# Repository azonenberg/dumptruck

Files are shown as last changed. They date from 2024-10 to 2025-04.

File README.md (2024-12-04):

# dumptruck
FPGA based dumper for flashes and more

## Main PCB errata

Bugs in the v0.1 PCB

* 1.0V shunt resistor is missing a zone fill. Will monitor droop under load and see if we need to add top layer power path.
* U33 is way too close to J10. Seems to have fit OK, not touching for now, but tough to assemble.
* INIT_B and PROG_B on FPGA are 1.8V signals but we try to drive with 3.3 from supervisor! Rework: add pull to 1.8V on board, open drain in super firmware
* JTAG connector VCC is connected to 3.3V. We need to supply 1.8 here. Temporary workaround: six pin extension cable, pass through JTAG + GND and supply 1.8V to dongle externally. Long term fix: interposer board
* DONE on FPGA is 1.8V signal driving 3.3V input on supervisor, too low for Vih. Rework: add 1.8V gate drive NMOS to pull low when done, invert logic in firmware

TODO: add HF caps to VCAP on STM32

## Breakout board errata

* v0.1 of parallel-nor-csp56 and dip8-qspi had EEPROM at 0xa0 which conflicted with MAC address EEPROM. Future breakouts use 0xa2 to avoid conflict

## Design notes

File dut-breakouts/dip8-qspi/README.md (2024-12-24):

# DIP8 QSPI flash

This board is intended to host either a DIP-8 QSPI flash (directly soldered or socketed), or a ZIF socket with
DIP-8 pinout for SOIC, DFN, etc.

Tested and validated sockets:
* DFN-8 (both 5x6 and 6x8 available) https://www.aliexpress.us/item/3256804610913861.html
* Narrow (150 mil) SOIC-8 https://www.aliexpress.us/item/2255799898445538.html

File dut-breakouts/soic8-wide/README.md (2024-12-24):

# soic8-wide

Breakout for wide (208 mil) SOIC-8

Designed for this socket https://www.aliexpress.us/item/3256807343973730.html

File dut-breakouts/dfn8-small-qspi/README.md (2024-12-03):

# dfn8-small-qspi

Breakout for small (5x6 mm) DFN-8 QSPI flashes.

Designed for this socket https://www.aliexpress.us/item/3256805075607192.html

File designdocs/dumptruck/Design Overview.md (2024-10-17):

* Powered by USB-C, CC pin tieoff for 900 mA power budget @ 5V, no PD, no USB data
	* One LTC3374A supplies all rails. 8 outputs among 4 phases
		* Have 3 in stock
	* Always-on 3V3_SB rail
	* Remainder (1V0, 1V2, 1V8, 2V5, 3V3) sequenced by supervisor
* STM32L431 rail sequencer / reset supervisor
	* QFN32 or QFN48 package depending on IO needs
	* GPIO for soft reset, power on/off
	* Have 7 or 8 in inventory depending on which package we go with
* Xilinx XC7S100-1FGGA484C
	* Have 3 in stock
	* Data link to host PC: 1000baseT via KSZ9031RNX
		* Have 13 in stock
	* HyperRAM footprint in case we want buffer on the FPGA
		* Infineon S27KS0642GABHI030
			* HyperBUS, 1.8V only, 200 MHz, 64 Mbit
			* Have 10 in stock
	* Boot flash: need minimum 32 Mbit
		* ISSI IS25WP256D-JLLE
			* 256 Mbit so room for multi-boot images
			* QSPI, 1.8V only, 8x6 WSON
			* Have 4 in stock
* STM32H735 as main processor
	* Have 9 in stock
	* HyperRAM in case we want buffer on the MCU?
		* Will need to account for OctoSPI errata, but this is probably OK if we're only using it for bulk data transfers.
		* Do not have any 3.3V HyperRAM in inventory. Leave DNP'd footprint
	* FMC to FPGA as primary I/O interface
	* AT24MAC402 for MAC address
		* Have a ton of these
* Four separate socket connectors (interface TBD, 0.1" header or something else?) for DUT ZIF sockets / BGA breakouts. Each one goes to a dedicated FPGA IO bank running at the target VCCO
* External 0.1" header with jumpers for muxing one of the four suitable IO rails as DUT Vcore
	* Can also feed externally generated Vcore in for unusual voltage requirements
	* No on-board variable Vcore supply
	* ADC input from Vcore to MCU so we know which is selected
* Software controlled load switch from muxed Vcore to DUT socket using NCP45525IMNTWG-H
	* Slew rate controlled, load discharge, active high enable
	* Requires external 3.3V supply
	* Can switch loads from 0.5 to 13.5V

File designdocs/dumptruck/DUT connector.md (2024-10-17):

* Samtec BSE-040 (80 contacts total)
* 8x support signals
	* 2x vcore
	* 2x vccio
	* Presence detect: pulled weakly low on host, tie to 3v3 on socket
	* 3v3 for ID EEPROM
	* I2C for ID EEPROM
* 50x GPIOs
* 22 grounds

## Pinout
1-14 support stuff, that leaves 66 left
50x GPIO + 16 grounds = one ground per 3.125 signals

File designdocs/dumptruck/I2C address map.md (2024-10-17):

## Supervisor bus

* INA230s:
	* VBUS: 0x80
	* 3V3_SB: 0x82
	* 3V3: 0x84
	* 2V5: 0x86
	* 1V8: 0x88
	* 1V2: 0x8a
	* 1V0: 0x8c
	* DUT_VDD: 0x8e
	* DUT_VCCIO 3V3: 0x90
	* DUT_VCCIO 2V5: 0x92
	* DUT_VCCIO 1V8: 0x94
	* DUT_VCCIO 1V2: 0x96
## Main MCU bus
* MAC EEPROM: 0xa0, 0xb0
* Socket ID EEPROM: 0xa2

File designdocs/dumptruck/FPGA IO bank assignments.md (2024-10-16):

## Available banks

We have seven banks available: 13, 14, 15, 16, 34, 35, 36 plus config bank 0.

All banks are HR and generally drop-in interchangeable, EXCEPT:
* QSPI flash pins are in bank 14
* Bank 13 has only 38 pins of 50 bonded out
## Requirements
* DUT sockets
	* Dedicate one full bank to each socket
	* Don't yet know how many pins we'll actually break out
* Boot flash
	* Bank 14, LVCMOS18, needs 4x SPI data + CS. CCLK is in bank 0
	* This means bank 0 must be LVCMOS18 as well (i.e. JTAG is 1.8V)
* HyperRAM
	* 12 pins, LVCMOS18
* Ethernet
	* 14 pins for RGMII + MDIO, assume reset driven by MCU not FPGA
	* Can do whatever voltage, but LVCMOS18 is least power
* FPGA - MCU interface
	* All LVCMOS33 to interface to MCU at full voltage
	* If we hook up optional addr/enable bits, we get 37 pins
	* Signals:
		* clk
		* nwait
		* noe
		* ad\[15:0\]
		* nwe
		* nbl\[1:0\]
		* nl_nadv
		* addr_hi\[25:0\]
			* Max of 26 address lines available, 15:0 are shared with AD so we can add up to another 10. Pin out as many as we can comfortably route
		* ne\[3:0\]
			* ne1 is the most important if we are using a standard config
			* Can't hurt to hook up the others if we have sufficient pins
## Tentative bank assignments
* Bank 13: 1.8V, 0 / 38 used
* Bank 14: 1.8V, 32 / 50 used
	* Boot flash (5)
	* HyperRAM (12)
	* RGMII (14 including 1 clock)
	* 25 MHz system primary clock
* Bank 15: 3.3V, 50 / 50 used
	* FMC interface
* Bank 16: 3.3V, ?? / 50 used
	* DUT socket
* Bank 36: 2.5V, ?? / 50 used
	* DUT socket
* Bank 35:  1.8V, ?? / 50 used
	* DUT socket
* Bank 34: 1.2V, ?? / 50 used
	* DUT socket

Rationale:
* Bank 14 must be 1.8V for boot flash, can shove basically all other non-MCU IO there
* Bank 13 has less pins, leave it for overflow capacity
* We want the DUT sockets in adjacent banks for routability. With 14 occupied by control stuff and 13 too small, we need to choose 4 out of 5 (34, 35, 36, 16, 15) as the DUT-facing banks. Using 15 as the other control bank seems logical so all control logic is on the same side of the FPGA.
* Bank 15 is 100% used for MCU interface and runs at 3.3V. Putting the 3.3V DUT bank in 16 simplifies power routing.
* Bank 36 is off in a corner so easier to route odd power voltage to
* Bank 35 is directly across from 14 separated by the FPGA core. Both banks, plus VCCAUX, need 1.8V so we can route a 1.8V polygon all the way across.
* Bank 34 is also in a corner so easy to route an odd voltage to

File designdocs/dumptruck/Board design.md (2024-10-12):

## Physical floorplan
* USB-C and Ethernet connectors along east edge
* FPGA near center with A1 in northwest corner
* MCU northeast
* Ethernet and boot flash southeast
* DUT sockets to west. May have overlapping mounting footprints as only one socket of the four will be mated at any given time
* Debug connectors along south edge
	* Bank 13 unused so can easily escape JTAG through this region
* Probably want power regulation in southeast
	* Can have a 3.3V pour snake around the edge of the board to get to the MCU area
	* Easy access to PHY and FPGA center
	* Maybe have 2.5V hook north and west to get to the bank there
## Fab / stackup
* We have a lot of power domains that need to get around
	* 3.3V only used by northeast area (MCU + DUT bank 16 IOs)
	* 2.5V used by northwest corner of FPGA plus PHY
		* Unless we run the PHY AVDDH at 3.3?
		* That might be easier since we have 3.3 in that general area from the MCU already, but will cost another ~75 mW of power
	* 1.8V used by center of FPGA, Ethernet, boot flash
	* 1.2V used by southwest corner of FPGA and Ethernet
	* 1.0V used by FPGA core only, feed in from south under bank 13 since no IOs there?
* Minimum one dedicated power layer but ideally would like some power on another layer
* Staying 6L would be nice, but tricky
	* That would allow oshpark 6L, this is slow enough fiber weave effect from the 106 PP is no factor
	* Possible stackup: SGS SGS with power pours on L3/L4 around signals?
		* Not great from an impedance matching perspective since the ground will couple and act as a CPWG but not provide a clean return path
		* Can't get large clearances from signals because of the BGA via field
* 8L probably better?
	* Possible stackup: SGS PP SGS
	* I really don't think 10L SGS GPPG SGS is necessary for this, but we do want four signal layers

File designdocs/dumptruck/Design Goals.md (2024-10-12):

* This is a "junk box build". Use components I have in inventory as much as possible, even if they're not necessarily optimal, unless there is a well defined reason not to.
* Be able to dump (or, with suitable firmware, program) any memory-ish chip I may encounter given an appropriate breakout adapter or ZIF socket
	* I2C EEPROM
	* (Q)SPI flash
	* Raw ONFI NAND
	* eMMC

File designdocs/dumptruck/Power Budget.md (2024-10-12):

## Breakdown

Target power budget: 900 mA @ 5V using USB3 host on type-C connector 4.5W

* KSZ9031 assuming 2.5V AVDDH: 452 mW
	* 1.2V @ 221 mA = 262 mW
	* 1.8V @ 23.6 mA = 43 mW
	* ONE OF
		* 2.5V @ 58.8 mA = 147 mW
		* 3.3V @ 67.4 mA = 222 mW
* STM32H735:
	* Worst case if using SMPS: 3.3V @ 130 mA = 429 mW
* Whatever the DUT uses
	* Random modern NAND (per die) total 546 mW
		* 2.5 or 3.3V Vcc @ 100 mA = 330 mW
		* 1.2V Vccq @  180 mA = 216 mW
* So far we're at total of 1.42W plus conversion losses
* XC7K160T considered since i had some gathering dust, but would be over power budget
* XC7S100-1FGGA484I: 1.78W plus whatever design uses beyond boot surge
	* Has 7 IO banks vs 8
	* 16K slices vs 25K
	* 120 BRAMs vs 325 (still has 480 kB SRAM)
	* Both have 8 CMTs, we dont care about DSPs
	* No GTX but we weren't gonna use those anyway
	* Should be more than big enough
	* Minimum power: 1.78W 
		* 148 + 9mA @ 1V0 + 300 + 60 during boot = 517 mW
		* 43 mA @ 1V8 + 140 during boot = 329 mW
		* No GTX supplies
		* No VCXAUX_IO
		* 4 mA VCCO + 40 mA per bank = 284 mA
			* Assume worst case 3.3V this is 937 mW
* So assuming design doesn't use much beyond boot surge, total power budget is 3.2W plus conversion losses. Comfortably fits in 4.5W target
* Maybe use a bit more for a HyperRAM on the STM32 if we wanted to play with that for lulz
* Add the usual small STM32L431 for rail sequencing and reset, this doesn't need much juice
* FPGA boot flash is negligible
## Rail Targets
* 1V0: 1A (~500 mA FPGA)
* 1V2: 1A (221 mA PHY + one FPGA VCCO bank)
* 1V8: 1A (180 mA FPGA + PHY IO + one FPGA VCCO bank)
* 2V5: 1A (60 mA PHY + one FPGA VCCO bank)
* 3V3: 1A (130 mA MCU + one FPGA VCCO bank)

Plus whatever the DUT actually needs on Vcore but we assume that's small
* Use MUN12AD03-SE for each rail? Easy and tiny, but really wants 12V in and has minimum Vin of 4.5V. Won't handle Vbus droop well.
* Use LTC3374A? Might be a bit noisier but this is a digital board without tight ripple requirements. It can do every rail comfortably, we can gang several phases to improve efficiency. This is probably best bet.

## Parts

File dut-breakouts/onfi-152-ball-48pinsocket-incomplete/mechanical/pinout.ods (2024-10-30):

BGA ball | Socket pin | Function | Cap C10 Is VCC to GND | Missing socket pins
D11 | -- | VCCQ |  | A1 | nc?
D3 | C2 | VCCQ |  | A3 | nc?
D4 | C4 | VCCQ |  | A5 | nc?
D5 | B3 | DQ3_1 |  | A7 | nc?
D6 | E1 | GND |  | B1 | nc?
D8 | F1 | VCC |  | B5 | nc?
D9 |  | DQ4_1 |  | B8 | nc?
E10 |  | DQ5_1 |  | C6 | nc?
E11 | A4 | GND |  | C8 | nc?
E3 | E8 | GND |  | D1 | nc?
E4 | C3 | DQ2_1 |  | E2 | nc?
E5 | D4 | GND |  | E5 | nc?
E6 | B4 | DQS_1_P |  | F2 | nc?
E8 |  | RE_1_N |  | F8 | nc?
E9 | C1 | GND
F10 |  | DQ6_1
F11 |  | DQ7_1
F3 |  | DQ0_1
F4 | A2 | DQ1_1
F5 |  | DQS1_N
F6 |  | RE_1_P
F8 |  | WE1_N
F9 |  | VREF_1
G10 | -- | VCCQ
G11 | -- | GND
G3 | A8 | GND
G4 | -- | VCCQ
G5 | E3 | ALE_1
G6 | D3 | CLE_1
H10 |  | RZQ_1
H5 | D2 | WP1_N
H8 | E4 | CE1_1_N
H9 | F6 | CE0_1_N
J10 | C5 | VCC
J11 | -- | GND
J3 | -- | GND
J4 | F5 | VCC
J5 | F7 | R_B0_0
J6 | D7 | R_B1_0
J8 | E7 | R_B1_1
J9 | D6 | R_B0_1
K4 |  | RZQ_0
K5 | D5 | CE0_0_N
K6 | F4 | CE1_0_N
K8 |  | VPP
K9 |  | WP0_N
L10 | -- | VCCQ
L11 | -- | GND
L2 | -- | GND
L4 | -- | VCCQ
L8 |  | CLE_0
L9 |  | ALE_0
M10 |  | DQ1_0
M11 | B2 | DQ0_0
M3 | B7 | DQ7_0
M4 | C7 | DQ6_0
M5 |  | VREF_0
M6 | F3 | WE_0_N
M8 |  | RE_0
M9 |  | DQS_0_N
N10 |  | DQ2_0
N11 | -- | GND
N3 | -- | GND
N4 | A6 | DQ5_0
N5 | -- | GND
N6 | E6 | RE_0_N
N8 |  | DQS_0_P
N9 | -- | GND
P10 | -- | VCCQ
P11 | -- | VCCQ
P3 | -- | VCCQ
P4 | -- | VCCQ
P5 | B6 | DQ4_0
P6 | D8 | VCC
P8 | -- | GND
P9 |  | DQ3_0

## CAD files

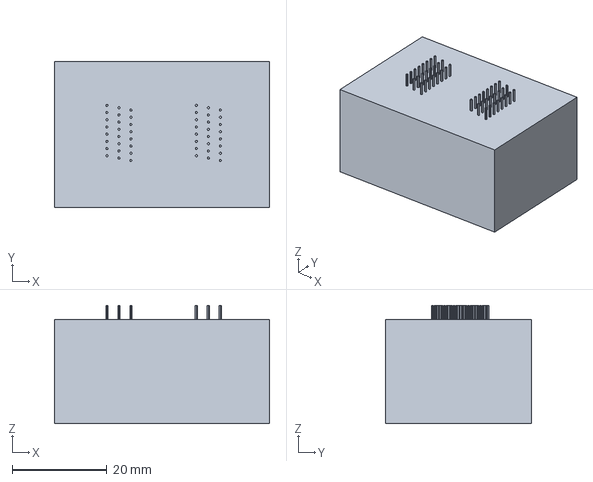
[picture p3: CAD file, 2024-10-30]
dut-breakouts/onfi-152-ball-48pinsocket-incomplete/mechanical/onfi-152-socket.step
45.5 x 31.0 x 25.0 mm

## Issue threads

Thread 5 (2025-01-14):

Improbable VDD voltage reported by CLI during dump

lainy, 2025-01-14:
```
[2000-02-01T04:49:13.9866] Power on request
[2000-02-01T04:49:13.9969]     VCCIO:  3.323V, 0.000A
[2000-02-01T04:49:13.9969]     VDD:    63.479V, 6.168A
[2000-02-01T04:49:13.9969]     VCCIO delta: 23 mV (OK)
```

azonenberg, 2025-01-15:
Likely related to communication between supervisor and main MCU. Could also be solder issue on one of the INA230s (U8, northeast corner).

Can you paste the output of "show hardware" in the CLI when the board is idle (not dumping)?

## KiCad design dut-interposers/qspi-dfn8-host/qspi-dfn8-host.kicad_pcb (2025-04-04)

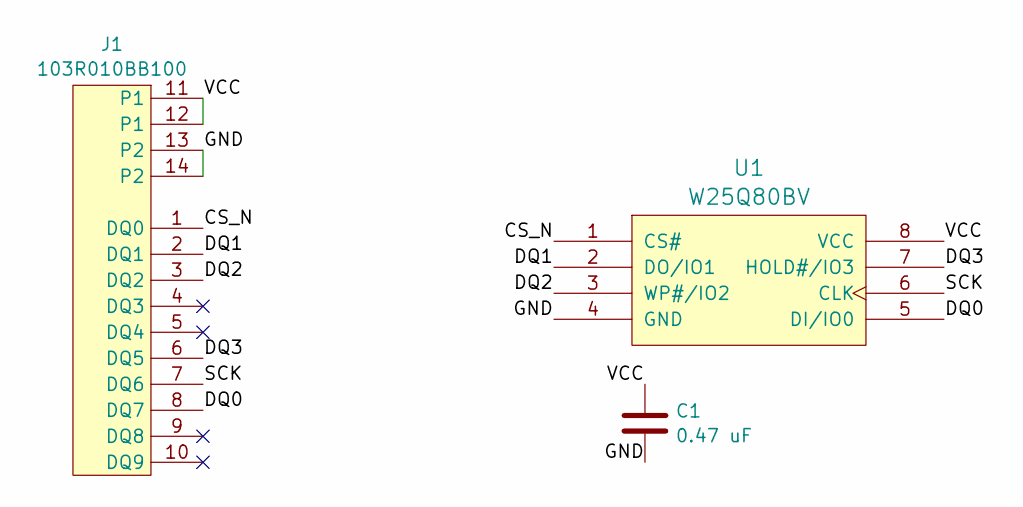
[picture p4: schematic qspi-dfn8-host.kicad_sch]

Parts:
C1: 0.47 uF; EIA_0402_CAP_NOSILK
J1: 103R010BB100; CONN_AMPHENOL_103R010BB100
U1: W25Q80BV; DFN_8_0.5MM_2x3MM_TALL

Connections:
/CS_N: J1.1 (DQ0), U1.1 (CS#)
/DQ0: J1.8 (DQ7), U1.5 (DI/IO0)
/DQ1: J1.2 (DQ1), U1.2 (DO/IO1)
/DQ2: J1.3 (DQ2), U1.3 (WP#/IO2)
/DQ3: J1.6 (DQ5), U1.7 (HOLD#/IO3)
/GND: C1.2, J1.13 (P2), J1.14 (P2), U1.4 (GND)
/SCK: J1.7 (DQ6), U1.6 (CLK)
/VCC: C1.1, J1.11 (P1), J1.12 (P1), U1.8 (VCC)

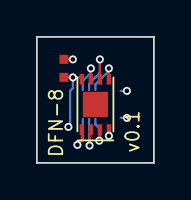
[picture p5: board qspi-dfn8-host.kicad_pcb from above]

Board: 4 copper layers, 6.5 x 7.0 mm, 3 parts (1 on the bottom side), 8 nets.

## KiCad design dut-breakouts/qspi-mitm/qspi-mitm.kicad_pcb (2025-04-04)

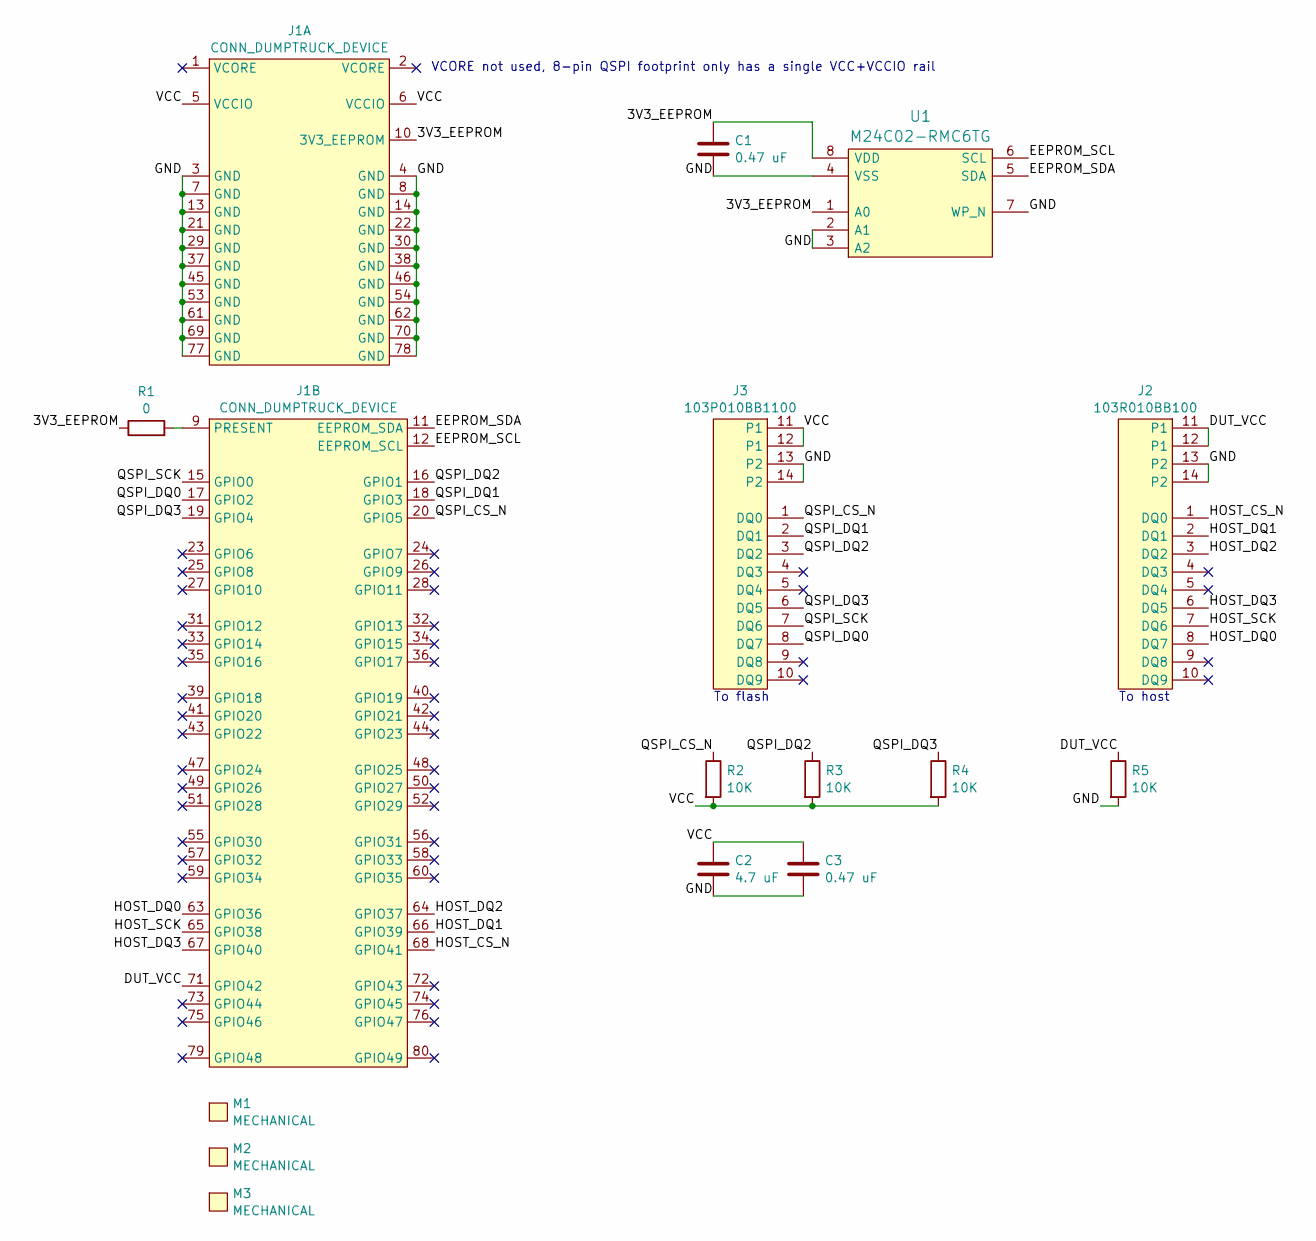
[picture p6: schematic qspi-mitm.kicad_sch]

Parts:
C1, C3: 0.47 uF; EIA_0402_CAP_NOSILK
C2: 4.7 uF; EIA_0603_CAP_NOSILK
J1: CONN_DUMPTRUCK_DEVICE; CONN_SAMTEC_BSE-040-01-L-D-A-TR
J2: 103R010BB100; CONN_AMPHENOL_103R010BB100
J3: 103P010BB1100; CONN_AMPHENOL_103P010BB100
M1: MECHANICAL; Logo_silk_ROHS_5x2.8mm
M2: MECHANICAL; Logo_silk_OSHW_6x6mm
M3: MECHANICAL; Logo_silk_WEEE_3.4x5mm
R1: 0; EIA_0402_RES_NOSILK
R2, R3, R4, R5: 10K; EIA_0402_RES_NOSILK
U1: M24C02-RMC6TG; DFN_8_0.5MM_2x3MM_TALL

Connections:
/3V3_EEPROM: C1.1, J1.10 (3V3_EEPROM), R1.1, U1.1 (A0), U1.8 (VDD)
/DUT_VCC: J1.71 (GPIO42), J2.11 (P1), J2.12 (P1), R5.1
/EEPROM_SCL: J1.12 (EEPROM_SCL), U1.6 (SCL)
/EEPROM_SDA: J1.11 (EEPROM_SDA), U1.5 (SDA)
/GND: C1.2, C2.2, C3.2, J1.3 (GND), J1.4 (GND), J1.7 (GND), J1.8 (GND), J1.13 (GND), J1.14 (GND), J1.21 (GND), J1.22 (GND), J1.29 (GND), J1.30 (GND), J1.37 (GND), J1.38 (GND), J1.45 (GND), J1.46 (GND), J1.53 (GND), J1.54 (GND), J1.61 (GND), J1.62 (GND), J1.69 (GND), J1.70 (GND), J1.77 (GND), J1.78 (GND), J2.13 (P2), J2.14 (P2), J3.13 (P2), J3.14 (P2), R5.2, U1.2 (A1), U1.3 (A2), U1.4 (VSS), U1.7 (WP_N)
/HOST_CS_N: J1.68 (GPIO41), J2.1 (DQ0)
/HOST_DQ0: J1.63 (GPIO36), J2.8 (DQ7)
/HOST_DQ1: J1.66 (GPIO39), J2.2 (DQ1)
/HOST_DQ2: J1.64 (GPIO37), J2.3 (DQ2)
/HOST_DQ3: J1.67 (GPIO40), J2.6 (DQ5)
/HOST_SCK: J1.65 (GPIO38), J2.7 (DQ6)
/QSPI_CS_N: J1.20 (GPIO5), J3.1 (DQ0), R2.1
/QSPI_DQ0: J1.17 (GPIO2), J3.8 (DQ7)
/QSPI_DQ1: J1.18 (GPIO3), J3.2 (DQ1)
/QSPI_DQ2: J1.16 (GPIO1), J3.3 (DQ2), R3.1
/QSPI_DQ3: J1.19 (GPIO4), J3.6 (DQ5), R4.1
/QSPI_SCK: J1.15 (GPIO0), J3.7 (DQ6)
/VCC: C2.1, C3.1, J1.5 (VCCIO), J1.6 (VCCIO), J3.11 (P1), J3.12 (P1), R2.2, R3.2, R4.2
unnamed: J1.9 (PRESENT), R1.2

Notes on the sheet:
To host
VCORE not used, 8-pin QSPI footprint only has a single VCC+VCCIO rail
To flash

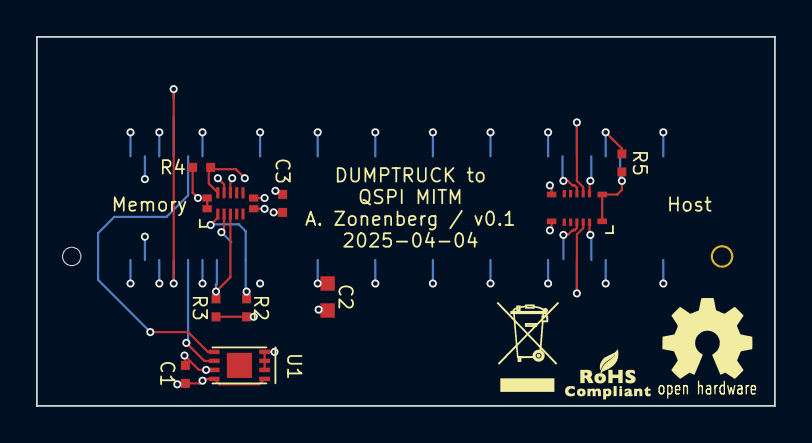
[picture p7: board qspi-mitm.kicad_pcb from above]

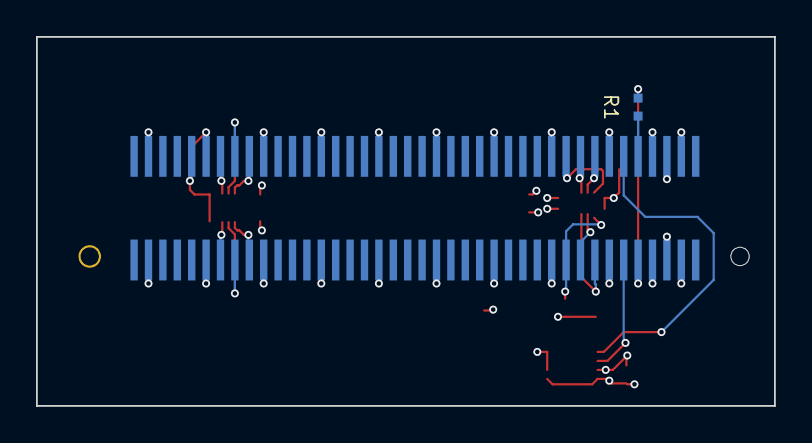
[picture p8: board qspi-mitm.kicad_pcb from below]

Board: 4 copper layers, 41.0 x 20.5 mm, 15 parts (2 on the bottom side), 19 nets.

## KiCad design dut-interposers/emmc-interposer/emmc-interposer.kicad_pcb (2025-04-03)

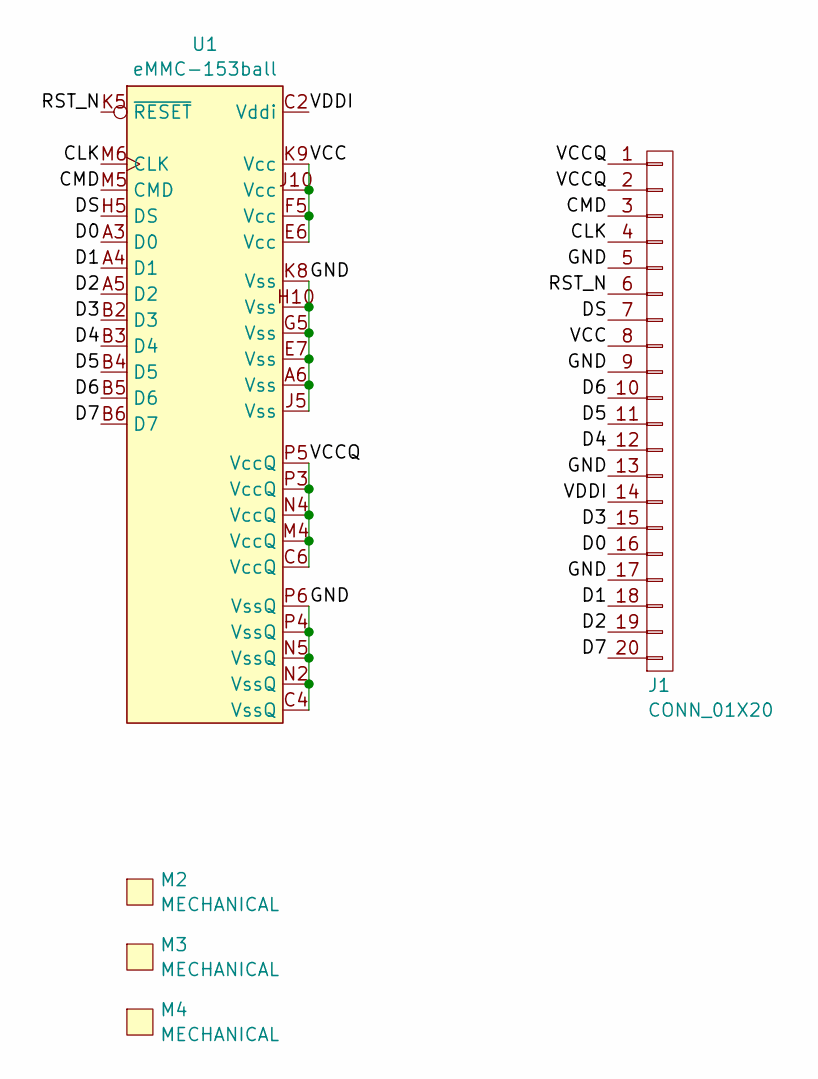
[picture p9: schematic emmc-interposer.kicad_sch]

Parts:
J1: CONN_01X20; CONN_FFC_0.5MM_3.5MM_1x20_2MM
M2: MECHANICAL; Logo_silk_OSHW_6x6mm
M3: MECHANICAL; Logo_silk_WEEE_3.4x5mm
M4: MECHANICAL; Logo_silk_ROHS_5x2.8mm
U1: eMMC-153ball; BGA_153_14x14_EMMC_BA_0.5MM_NCDEPOP_REVERSE

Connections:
/CLK: J1.4, U1.M6 (CLK)
/CMD: J1.3, U1.M5 (CMD)
/D0: J1.16, U1.A3 (D0)
/D1: J1.18, U1.A4 (D1)
/D2: J1.19, U1.A5 (D2)
/D3: J1.15, U1.B2 (D3)
/D4: J1.12, U1.B3 (D4)
/D5: J1.11, U1.B4 (D5)
/D6: J1.10, U1.B5 (D6)
/D7: J1.20, U1.B6 (D7)
/DS: J1.7, U1.H5 (DS)
/GND: J1.5, J1.9, J1.13, J1.17, U1.A6 (Vss), U1.C4 (VssQ), U1.E7 (Vss), U1.G5 (Vss), U1.H10 (Vss), U1.J5 (Vss), U1.K8 (Vss), U1.N2 (VssQ), U1.N5 (VssQ), U1.P4 (VssQ), U1.P6 (VssQ)
/RST_N: J1.6, U1.K5 (~RESET)
/VCC: J1.8, U1.E6 (Vcc), U1.F5 (Vcc), U1.J10 (Vcc), U1.K9 (Vcc)
/VCCQ: J1.1, J1.2, U1.C6 (VccQ), U1.M4 (VccQ), U1.N4 (VccQ), U1.P3 (VccQ), U1.P5 (VccQ)
/VDDI: J1.14, U1.C2 (Vddi)

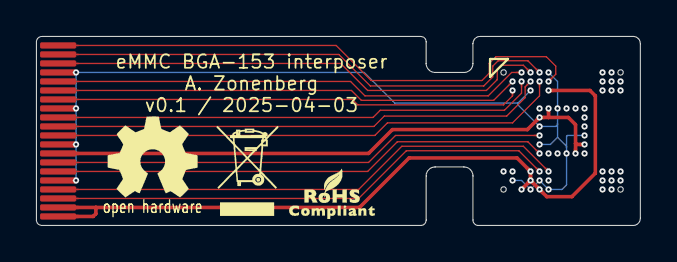
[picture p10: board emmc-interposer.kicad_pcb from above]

Board: 2 copper layers, 33.5 x 10.5 mm, 5 parts (0 on the bottom side), 16 nets.

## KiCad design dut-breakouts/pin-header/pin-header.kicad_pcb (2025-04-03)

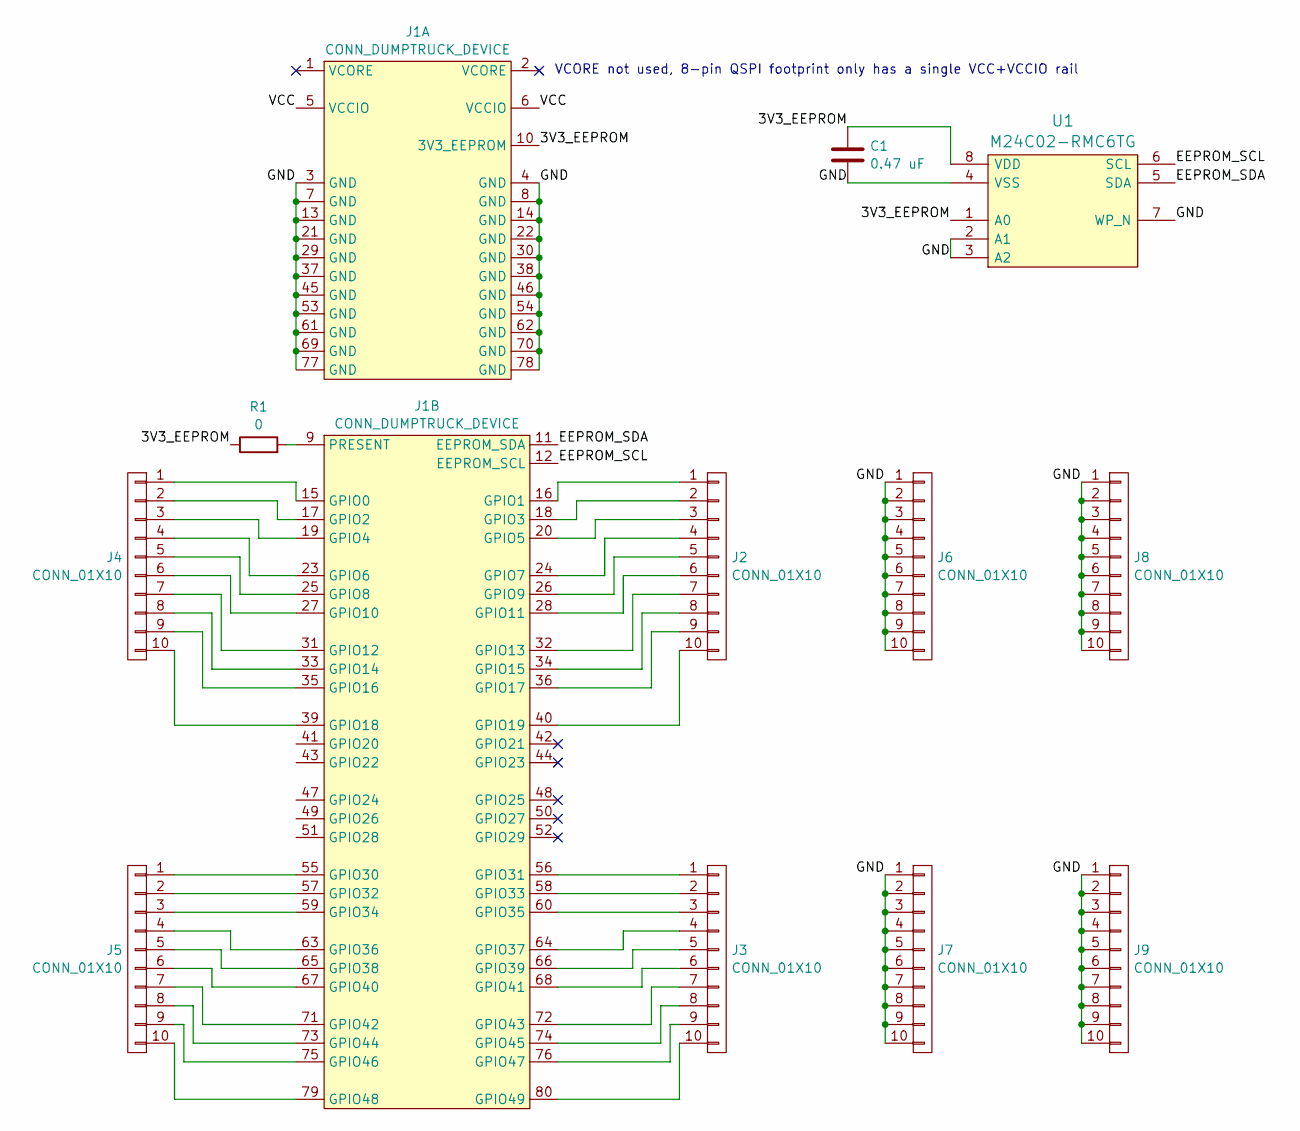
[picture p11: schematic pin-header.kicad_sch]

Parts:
C1: 0.47 uF; EIA_0402_CAP_NOSILK
J1: CONN_DUMPTRUCK_DEVICE; CONN_SAMTEC_BSE-040-01-L-D-A-TR
J2, J3, J4, J5, J6, J7, J8, J9: CONN_01X10; CONN_HEADER_2.54MM_1x10_REFLOW_NOSILK
R1: 0; EIA_0402_RES_NOSILK
U1: M24C02-RMC6TG; DFN_8_0.5MM_2x3MM_TALL

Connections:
/3V3_EEPROM: C1.1, J1.10 (3V3_EEPROM), R1.1, U1.1 (A0), U1.8 (VDD)
/EEPROM_SCL: J1.12 (EEPROM_SCL), U1.6 (SCL)
/EEPROM_SDA: J1.11 (EEPROM_SDA), U1.5 (SDA)
/GND: C1.2, J1.3 (GND), J1.4 (GND), J1.7 (GND), J1.8 (GND), J1.13 (GND), J1.14 (GND), J1.21 (GND), J1.22 (GND), J1.29 (GND), J1.30 (GND), J1.37 (GND), J1.38 (GND), J1.45 (GND), J1.46 (GND), J1.53 (GND), J1.54 (GND), J1.61 (GND), J1.62 (GND), J1.69 (GND), J1.70 (GND), J1.77 (GND), J1.78 (GND), J6.1, J6.2, J6.3, J6.4, J6.5, J6.6, J6.7, J6.8, J6.9, J6.10, J7.1, J7.2, J7.3, J7.4, J7.5, J7.6, J7.7, J7.8, J7.9, J7.10, J8.1, J8.2, J8.3, J8.4, J8.5, J8.6, J8.7, J8.8, J8.9, J8.10, J9.1, J9.2, J9.3, J9.4, J9.5, J9.6, J9.7, J9.8, J9.9, J9.10, U1.2 (A1), U1.3 (A2), U1.4 (VSS), U1.7 (WP_N)
/VCC: J1.5 (VCCIO), J1.6 (VCCIO)
unnamed: J1.15 (GPIO0), J4.1
unnamed: J1.16 (GPIO1), J2.1
unnamed: J1.17 (GPIO2), J4.2
unnamed: J1.18 (GPIO3), J2.2
unnamed: J1.19 (GPIO4), J4.3
unnamed: J1.20 (GPIO5), J2.3
unnamed: J1.23 (GPIO6), J4.4
unnamed: J1.24 (GPIO7), J2.4
unnamed: J1.25 (GPIO8), J4.5
unnamed: J1.26 (GPIO9), J2.5
unnamed: J1.27 (GPIO10), J4.6
unnamed: J1.28 (GPIO11), J2.6
unnamed: J1.31 (GPIO12), J4.7
unnamed: J1.32 (GPIO13), J2.7
unnamed: J1.33 (GPIO14), J4.8
unnamed: J1.34 (GPIO15), J2.8
unnamed: J1.35 (GPIO16), J4.9
unnamed: J1.36 (GPIO17), J2.9
unnamed: J1.39 (GPIO18), J4.10
unnamed: J1.40 (GPIO19), J2.10
unnamed: J1.55 (GPIO30), J5.1
unnamed: J1.56 (GPIO31), J3.1
unnamed: J1.57 (GPIO32), J5.2
unnamed: J1.58 (GPIO33), J3.2
unnamed: J1.59 (GPIO34), J5.3
unnamed: J1.60 (GPIO35), J3.3
unnamed: J1.63 (GPIO36), J5.4
unnamed: J1.64 (GPIO37), J3.4
unnamed: J1.65 (GPIO38), J5.5
unnamed: J1.66 (GPIO39), J3.5
unnamed: J1.67 (GPIO40), J5.6
unnamed: J1.68 (GPIO41), J3.6
unnamed: J1.71 (GPIO42), J5.7
unnamed: J1.72 (GPIO43), J3.7
unnamed: J1.73 (GPIO44), J5.8
unnamed: J1.74 (GPIO45), J3.8
unnamed: J1.75 (GPIO46), J5.9
unnamed: J1.76 (GPIO47), J3.9
unnamed: J1.79 (GPIO48), J5.10
unnamed: J1.80 (GPIO49), J3.10
unnamed: J1.9 (PRESENT), R1.2

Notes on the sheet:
VCORE not used, 8-pin QSPI footprint only has a single VCC+VCCIO rail

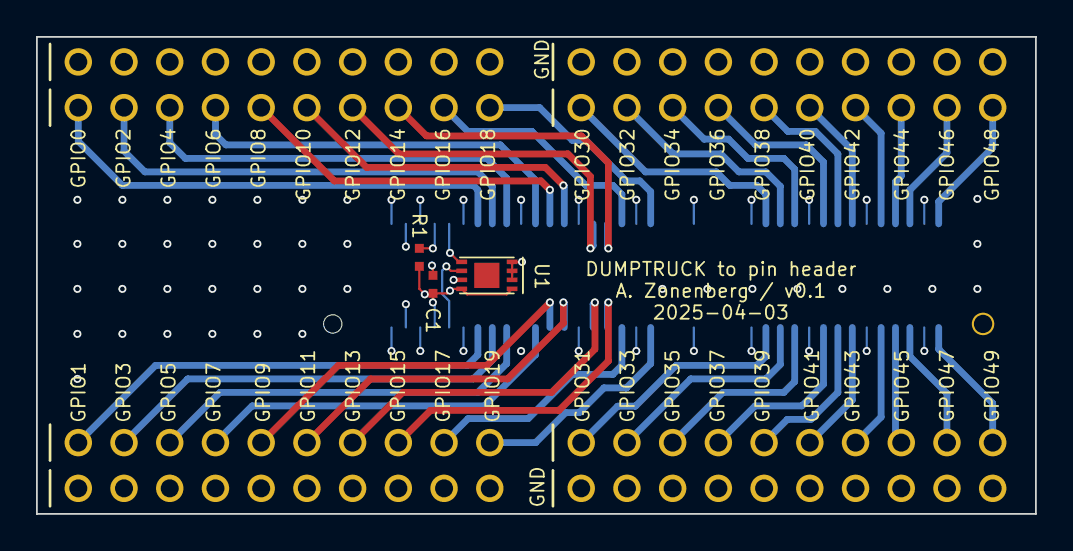
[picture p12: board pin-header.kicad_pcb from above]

Board: 4 copper layers, 55.5 x 26.5 mm, 12 parts (1 on the bottom side), 46 nets.

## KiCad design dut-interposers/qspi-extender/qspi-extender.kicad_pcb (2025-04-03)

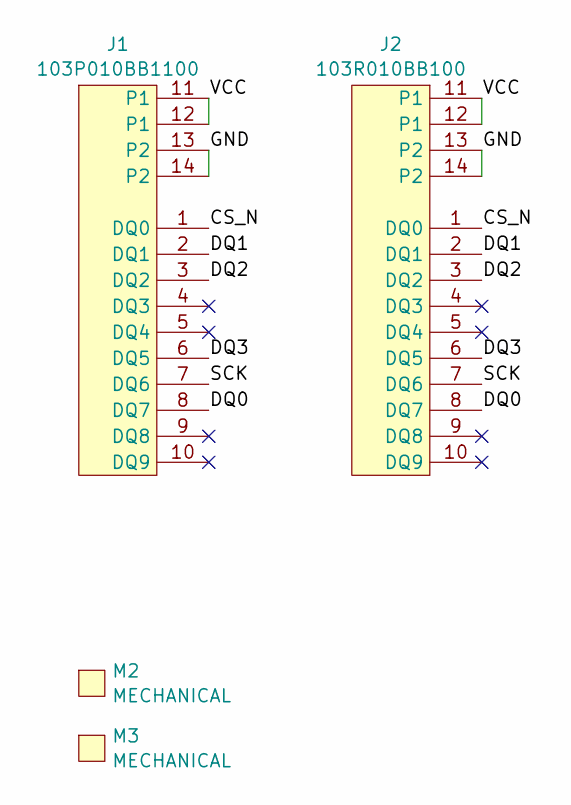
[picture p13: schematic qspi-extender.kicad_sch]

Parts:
J1: 103P010BB1100; CONN_AMPHENOL_103P010BB100
J2: 103R010BB100; CONN_AMPHENOL_103R010BB100
M2: MECHANICAL; Logo_silk_ROHS_5x2.8mm
M3: MECHANICAL; Logo_silk_OSHW_6x6mm

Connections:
/CS_N: J1.1 (DQ0), J2.1 (DQ0)
/DQ0: J1.8 (DQ7), J2.8 (DQ7)
/DQ1: J1.2 (DQ1), J2.2 (DQ1)
/DQ2: J1.3 (DQ2), J2.3 (DQ2)
/DQ3: J1.6 (DQ5), J2.6 (DQ5)
/GND: J1.13 (P2), J1.14 (P2), J2.13 (P2), J2.14 (P2)
/SCK: J1.7 (DQ6), J2.7 (DQ6)
/VCC: J1.11 (P1), J1.12 (P1), J2.11 (P1), J2.12 (P1)

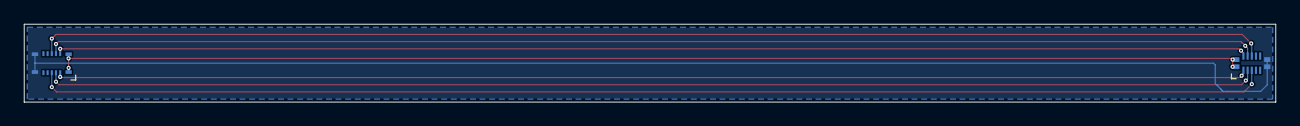
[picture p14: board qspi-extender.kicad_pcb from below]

Board: 2 copper layers, 104.5 x 6.5 mm, 4 parts (2 on the bottom side), 8 nets.

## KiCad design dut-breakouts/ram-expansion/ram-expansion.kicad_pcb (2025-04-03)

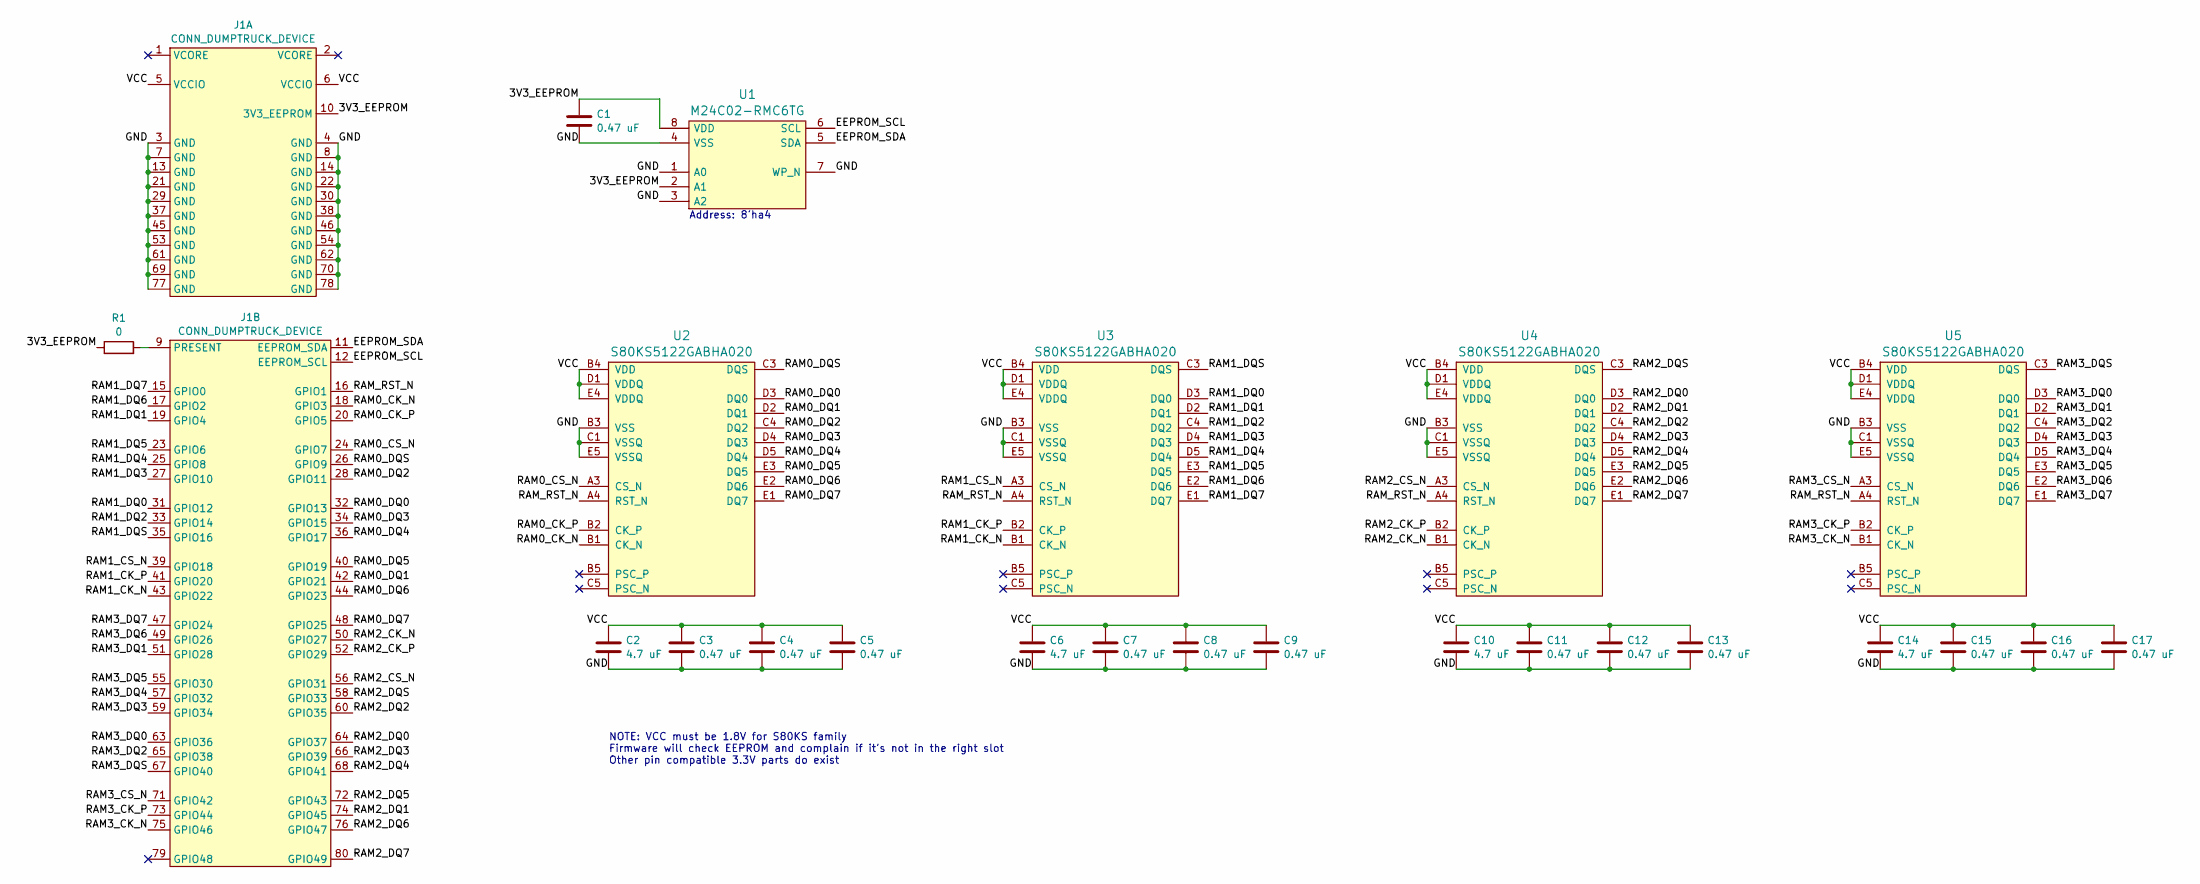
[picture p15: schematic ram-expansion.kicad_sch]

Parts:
C1, C3, C4, C5, C7, C8, C9, C11, C12, C13, C15, C16, C17: 0.47 uF; EIA_0402_CAP_NOSILK
C2, C6, C10, C14: 4.7 uF; EIA_0603_CAP_NOSILK
J1: CONN_DUMPTRUCK_DEVICE; CONN_SAMTEC_BSE-040-01-L-D-A-TR
R1: 0; EIA_0402_RES_NOSILK
U1: M24C02-RMC6TG; DFN_8_0.5MM_2x3MM_TALL
U2, U3, U4, U5: S80KS5122GABHA020; BGA_24_6x8_DEPOP1_1MM

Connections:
/3V3_EEPROM: C1.1, J1.10 (3V3_EEPROM), R1.1, U1.2 (A1), U1.8 (VDD)
/EEPROM_SCL: J1.12 (EEPROM_SCL), U1.6 (SCL)
/EEPROM_SDA: J1.11 (EEPROM_SDA), U1.5 (SDA)
/GND: C1.2, C2.2, C3.2, C4.2, C5.2, C6.2, C7.2, C8.2, C9.2, C10.2, C11.2, C12.2, C13.2, C14.2, C15.2, C16.2, C17.2, J1.3 (GND), J1.4 (GND), J1.7 (GND), J1.8 (GND), J1.13 (GND), J1.14 (GND), J1.21 (GND), J1.22 (GND), J1.29 (GND), J1.30 (GND), J1.37 (GND), J1.38 (GND), J1.45 (GND), J1.46 (GND), J1.53 (GND), J1.54 (GND), J1.61 (GND), J1.62 (GND), J1.69 (GND), J1.70 (GND), J1.77 (GND), J1.78 (GND), U1.1 (A0), U1.3 (A2), U1.4 (VSS), U1.7 (WP_N), U2.B3 (VSS), U2.C1 (VSSQ), U2.E5 (VSSQ), U3.B3 (VSS), U3.C1 (VSSQ), U3.E5 (VSSQ), U4.B3 (VSS), U4.C1 (VSSQ), U4.E5 (VSSQ), U5.B3 (VSS), U5.C1 (VSSQ), U5.E5 (VSSQ)
/RAM0_CK_N: J1.18 (GPIO3), U2.B1 (CK_N)
/RAM0_CK_P: J1.20 (GPIO5), U2.B2 (CK_P)
/RAM0_CS_N: J1.24 (GPIO7), U2.A3 (CS_N)
/RAM0_DQ0: J1.32 (GPIO13), U2.D3 (DQ0)
/RAM0_DQ1: J1.42 (GPIO21), U2.D2 (DQ1)
/RAM0_DQ2: J1.28 (GPIO11), U2.C4 (DQ2)
/RAM0_DQ3: J1.34 (GPIO15), U2.D4 (DQ3)
/RAM0_DQ4: J1.36 (GPIO17), U2.D5 (DQ4)
/RAM0_DQ5: J1.40 (GPIO19), U2.E3 (DQ5)
/RAM0_DQ6: J1.44 (GPIO23), U2.E2 (DQ6)
/RAM0_DQ7: J1.48 (GPIO25), U2.E1 (DQ7)
/RAM0_DQS: J1.26 (GPIO9), U2.C3 (DQS)
/RAM1_CK_N: J1.43 (GPIO22), U3.B1 (CK_N)
/RAM1_CK_P: J1.41 (GPIO20), U3.B2 (CK_P)
/RAM1_CS_N: J1.39 (GPIO18), U3.A3 (CS_N)
/RAM1_DQ0: J1.31 (GPIO12), U3.D3 (DQ0)
/RAM1_DQ1: J1.19 (GPIO4), U3.D2 (DQ1)
/RAM1_DQ2: J1.33 (GPIO14), U3.C4 (DQ2)
/RAM1_DQ3: J1.27 (GPIO10), U3.D4 (DQ3)
/RAM1_DQ4: J1.25 (GPIO8), U3.D5 (DQ4)
/RAM1_DQ5: J1.23 (GPIO6), U3.E3 (DQ5)
/RAM1_DQ6: J1.17 (GPIO2), U3.E2 (DQ6)
/RAM1_DQ7: J1.15 (GPIO0), U3.E1 (DQ7)
/RAM1_DQS: J1.35 (GPIO16), U3.C3 (DQS)
/RAM2_CK_N: J1.50 (GPIO27), U4.B1 (CK_N)
/RAM2_CK_P: J1.52 (GPIO29), U4.B2 (CK_P)
/RAM2_CS_N: J1.56 (GPIO31), U4.A3 (CS_N)
/RAM2_DQ0: J1.64 (GPIO37), U4.D3 (DQ0)
/RAM2_DQ1: J1.74 (GPIO45), U4.D2 (DQ1)
/RAM2_DQ2: J1.60 (GPIO35), U4.C4 (DQ2)
/RAM2_DQ3: J1.66 (GPIO39), U4.D4 (DQ3)
/RAM2_DQ4: J1.68 (GPIO41), U4.D5 (DQ4)
/RAM2_DQ5: J1.72 (GPIO43), U4.E3 (DQ5)
/RAM2_DQ6: J1.76 (GPIO47), U4.E2 (DQ6)
/RAM2_DQ7: J1.80 (GPIO49), U4.E1 (DQ7)
/RAM2_DQS: J1.58 (GPIO33), U4.C3 (DQS)
/RAM3_CK_N: J1.75 (GPIO46), U5.B1 (CK_N)
/RAM3_CK_P: J1.73 (GPIO44), U5.B2 (CK_P)
/RAM3_CS_N: J1.71 (GPIO42), U5.A3 (CS_N)
/RAM3_DQ0: J1.63 (GPIO36), U5.D3 (DQ0)
/RAM3_DQ1: J1.51 (GPIO28), U5.D2 (DQ1)
/RAM3_DQ2: J1.65 (GPIO38), U5.C4 (DQ2)
/RAM3_DQ3: J1.59 (GPIO34), U5.D4 (DQ3)
/RAM3_DQ4: J1.57 (GPIO32), U5.D5 (DQ4)
/RAM3_DQ5: J1.55 (GPIO30), U5.E3 (DQ5)
/RAM3_DQ6: J1.49 (GPIO26), U5.E2 (DQ6)
/RAM3_DQ7: J1.47 (GPIO24), U5.E1 (DQ7)
/RAM3_DQS: J1.67 (GPIO40), U5.C3 (DQS)
/RAM_RST_N: J1.16 (GPIO1), U2.A4 (RST_N), U3.A4 (RST_N), U4.A4 (RST_N), U5.A4 (RST_N)
/VCC: C2.1, C3.1, C4.1, C5.1, C6.1, C7.1, C8.1, C9.1, C10.1, C11.1, C12.1, C13.1, C14.1, C15.1, C16.1, C17.1, J1.5 (VCCIO), J1.6 (VCCIO), U2.B4 (VDD), U2.D1 (VDDQ), U2.E4 (VDDQ), U3.B4 (VDD), U3.D1 (VDDQ), U3.E4 (VDDQ), U4.B4 (VDD), U4.D1 (VDDQ), U4.E4 (VDDQ), U5.B4 (VDD), U5.D1 (VDDQ), U5.E4 (VDDQ)
unnamed: J1.9 (PRESENT), R1.2

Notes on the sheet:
Address: 8'ha4
NOTE: VCC must be 1.8V for S80KS family Firmware will check EEPROM and complain if it's not in the right slot Other pin compatible 3.3V parts do exist



Board: 4 copper layers, 40.2 x 21.8 mm, 24 parts (13 on the bottom side), 55 nets.

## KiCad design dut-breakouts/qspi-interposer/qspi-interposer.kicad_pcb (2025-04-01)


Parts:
C1: 0.47 uF; EIA_0402_CAP_NOSILK
C2, C4: 4.7 uF; EIA_0603_CAP_NOSILK
J1: CONN_DUMPTRUCK_DEVICE; CONN_SAMTEC_BSE-040-01-L-D-A-TR
J2: 103P010BB1100; CONN_AMPHENOL_103P010BB100
R1: 0; EIA_0402_RES_NOSILK
R2, R3, R4: 10K; EIA_0402_RES_NOSILK
U1: M24C02-RMC6TG; DFN_8_0.5MM_2x3MM_TALL

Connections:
/3V3_EEPROM: C1.1, J1.10 (3V3_EEPROM), R1.1, U1.1 (A0), U1.8 (VDD)
/EEPROM_SCL: J1.12 (EEPROM_SCL), U1.6 (SCL)
/EEPROM_SDA: J1.11 (EEPROM_SDA), U1.5 (SDA)
/GND: C1.2, C2.2, C4.2, J1.3 (GND), J1.4 (GND), J1.7 (GND), J1.8 (GND), J1.13 (GND), J1.14 (GND), J1.21 (GND), J1.22 (GND), J1.29 (GND), J1.30 (GND), J1.37 (GND), J1.38 (GND), J1.45 (GND), J1.46 (GND), J1.53 (GND), J1.54 (GND), J1.61 (GND), J1.62 (GND), J1.69 (GND), J1.70 (GND), J1.77 (GND), J1.78 (GND), J2.13 (P2), J2.14 (P2), U1.2 (A1), U1.3 (A2), U1.4 (VSS), U1.7 (WP_N)
/QSPI_CS_N: J1.20 (GPIO5), J2.1 (DQ0), R2.1
/QSPI_DQ0: J1.17 (GPIO2), J2.8 (DQ7)
/QSPI_DQ1: J1.18 (GPIO3), J2.2 (DQ1)
/QSPI_DQ2: J1.16 (GPIO1), J2.3 (DQ2), R3.1
/QSPI_DQ3: J1.19 (GPIO4), J2.6 (DQ5), R4.1
/QSPI_SCK: J1.15 (GPIO0), J2.7 (DQ6)
/VCC: C2.1, J1.5 (VCCIO), J1.6 (VCCIO), J2.11 (P1), J2.12 (P1), R2.2, R3.2, R4.2
/VCORE: C4.1, J1.2 (VCORE), J2.10 (DQ9)
unnamed: J1.9 (PRESENT), R1.2

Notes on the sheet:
VCORE pin not used in current interposers but hooked up for futureproofing



Board: 4 copper layers, 58.5 x 20.5 mm, 10 parts (2 on the bottom side), 13 nets.

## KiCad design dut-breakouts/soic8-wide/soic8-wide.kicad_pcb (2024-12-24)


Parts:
C1, C3: 0.47 uF; EIA_0402_CAP_NOSILK
C2: 4.7 uF; EIA_0603_CAP_NOSILK
J1: CONN_DUMPTRUCK_DEVICE; CONN_SAMTEC_BSE-040-01-L-D-A-TR
R1: 0; EIA_0402_RES_NOSILK
R2, R3, R4: 10K; EIA_0402_RES_NOSILK
U1: M24C02-RMC6TG; DFN_8_0.5MM_2x3MM_TALL
U2: DUT_SOCKET; SOIC_8_5.3MM

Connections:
/3V3_EEPROM: C1.1, J1.10 (3V3_EEPROM), R1.1, U1.1 (A0), U1.8 (VDD)
/EEPROM_SCL: J1.12 (EEPROM_SCL), U1.6 (SCL)
/EEPROM_SDA: J1.11 (EEPROM_SDA), U1.5 (SDA)
/GND: C1.2, C2.2, C3.2, J1.3 (GND), J1.4 (GND), J1.7 (GND), J1.8 (GND), J1.13 (GND), J1.14 (GND), J1.21 (GND), J1.22 (GND), J1.29 (GND), J1.30 (GND), J1.37 (GND), J1.38 (GND), J1.45 (GND), J1.46 (GND), J1.53 (GND), J1.54 (GND), J1.61 (GND), J1.62 (GND), J1.69 (GND), J1.70 (GND), J1.77 (GND), J1.78 (GND), U1.2 (A1), U1.3 (A2), U1.4 (VSS), U1.7 (WP_N), U2.4 (GND)
/QSPI_CS_N: J1.20 (GPIO5), R2.1, U2.1 (CS#)
/QSPI_DQ0: J1.17 (GPIO2), U2.5 (DI/IO0)
/QSPI_DQ1: J1.18 (GPIO3), U2.2 (DO/IO1)
/QSPI_DQ2: J1.16 (GPIO1), R3.1, U2.3 (WP#/IO2)
/QSPI_DQ3: J1.19 (GPIO4), R4.1, U2.7 (HOLD#/IO3)
/QSPI_SCK: J1.15 (GPIO0), U2.6 (CLK)
/VCC: C2.1, C3.1, J1.5 (VCCIO), J1.6 (VCCIO), R2.2, R3.2, R4.2, U2.8 (VCC)
unnamed: J1.9 (PRESENT), R1.2

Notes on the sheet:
VCORE not used, 8-pin QSPI footprint only has a single VCC+VCCIO rail



Board: 4 copper layers, 52.5 x 20.5 mm, 10 parts (2 on the bottom side), 12 nets.

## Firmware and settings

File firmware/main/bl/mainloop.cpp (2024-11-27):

/***********************************************************************************************************************
*                                                                                                                      *
* DUMPTRUCK                                                                                                            *
*                                                                                                                      *
* Copyright (c) 2023-2024 Andrew D. Zonenberg and contributors                                                         *
* All rights reserved.                                                                                                 *
*                                                                                                                      *
* Redistribution and use in source and binary forms, with or without modification, are permitted provided that the     *
* following conditions are met:                                                                                        *
*                                                                                                                      *
*    * Redistributions of source code must retain the above copyright notice, this list of conditions, and the         *
*      following disclaimer.                                                                                           *
*                                                                                                                      *
*    * Redistributions in binary form must reproduce the above copyright notice, this list of conditions and the       *
*      following disclaimer in the documentation and/or other materials provided with the distribution.                *
*                                                                                                                      *
*    * Neither the name of the author nor the names of any contributors may be used to endorse or promote products     *
*      derived from this software without specific prior written permission.                                           *
*                                                                                                                      *
* THIS SOFTWARE IS PROVIDED BY THE AUTHORS "AS IS" AND ANY EXPRESS OR IMPLIED WARRANTIES, INCLUDING, BUT NOT LIMITED   *
* TO, THE IMPLIED WARRANTIES OF MERCHANTABILITY AND FITNESS FOR A PARTICULAR PURPOSE ARE DISCLAIMED. IN NO EVENT SHALL *
* THE AUTHORS BE HELD LIABLE FOR ANY DIRECT, INDIRECT, INCIDENTAL, SPECIAL, EXEMPLARY, OR CONSEQUENTIAL DAMAGES        *
* (INCLUDING, BUT NOT LIMITED TO, PROCUREMENT OF SUBSTITUTE GOODS OR SERVICES; LOSS OF USE, DATA, OR PROFITS; OR       *
* BUSINESS INTERRUPTION) HOWEVER CAUSED AND ON ANY THEORY OF LIABILITY, WHETHER IN CONTRACT, STRICT LIABILITY, OR TORT *
* (INCLUDING NEGLIGENCE OR OTHERWISE) ARISING IN ANY WAY OUT OF THE USE OF THIS SOFTWARE, EVEN IF ADVISED OF THE       *
* POSSIBILITY OF SUCH DAMAGE.                                                                                          *
*                                                                                                                      *
***********************************************************************************************************************/

#include "bootloader.h"
/*#include "BootloaderUDPProtocol.h"
#include "BootloaderTCPProtocol.h"
#include "BootloaderCLISessionContext.h"*/

//Application region of flash runs from the end of the bootloader (0x8020000)
//to the start of the KVS (0x080c0000), so 640 kB
//Firmware version string is put right after vector table by linker script at a constant address
uint32_t* const g_appVector  = reinterpret_cast<uint32_t*>(0x8020000);

//Offset of the version string (size of the vector table plus 32 byte alignment)
const uint32_t g_appVersionOffset = 0x2e0;

///@brief Output stream for local serial console
UARTOutputStream g_localConsoleOutputStream;
/*
///@brief Context data structure for local serial console
BootloaderCLISessionContext g_localConsoleSessionContext;

///@brief The SSH server
BootloaderSSHTransportServer* g_sshd = nullptr;
*/

extern bool g_bootAppPending;
extern uint32_t g_bootAppTimer;

///@brief Number of sectors in the image
const uint32_t g_flashSectorCount = 5;

///@brief Size of a sector
const uint32_t g_flashSectorSize = 128 * 1024;

///@brief Size of the image
const uint32_t g_appImageSize = g_flashSectorCount * g_flashSectorSize;

////////////////////////////////////////////////////////////////////////////////////////////////////////////////////////
// Hooks called by bootloader code

void Bootloader_Init()
{
	/*
	DoInitKVS();
	InitQSPI();
	InitFPGA();
	InitI2C();
	InitEEPROM();
	InitSFP();
	InitManagementPHY();
	InitEthernet();
	InitIP();

	RTC::Unlock();

	//Initialize the FPGA IRQ pin
	g_irq.SetPullMode(GPIOPin::PULL_DOWN);

	//Initialize the local console
	g_localConsoleOutputStream.Initialize(&g_cliUART);
	g_localConsoleSessionContext.Initialize(&g_localConsoleOutputStream, "localadmin");
	*/
}

void Bootloader_ClearRxBuffer()
{
}

void Bootloader_FinalCleanup()
{
	g_cliUART.Flush();
}

void BSP_MainLoop()
{
	Bootloader_MainLoop();
}

/*
void RegisterProtocolHandlers(IPv4Protocol& ipv4)
{
	static BootloaderTCPProtocol tcp(&ipv4);
	static BootloaderUDPProtocol udp(&ipv4);
	ipv4.UseTCP(&tcp);
	ipv4.UseUDP(&udp);
	g_dhcpClient = &udp.GetDHCP();
}*/

////////////////////////////////////////////////////////////////////////////////////////////////////////////////////////
// Run the firmware updater

void __attribute__((noreturn)) Bootloader_FirmwareUpdateFlow()
{
	g_log("In DFU mode\n");

	//Show the initial prompt
	//g_localConsoleSessionContext.PrintPrompt();

	while(1)
	{
		/*
		//Main event loop
		static uint32_t next1HzTick = 0;
		static uint32_t next10HzTick = 0;
		static uint32_t nextPhyPoll = 0;
		const uint32_t logTimerMax = 0xf0000000;

		//Wait for an interrupt
		//asm("wfi");

		//Check if anything happened on the FPGA
		CheckForFPGAEvents();

		//Check if we had a PHY link state change at 20 Hz
		//TODO: add irq bit for this so we don't have to poll nonstop
		if(g_logTimer.GetCount() >= nextPhyPoll)
		{
			PollPHYs();
			nextPhyPoll = g_logTimer.GetCount() + 500;
		}

		//Check if we had an optic inserted or removed
		PollSFP();

		//Poll for UART input
		if(g_cliUART.HasInput())
			g_localConsoleSessionContext.OnKeystroke(g_cliUART.BlockingRead());

		if(g_log.UpdateOffset(logTimerMax))
		{
			next1HzTick -= logTimerMax;
			next10HzTick -= logTimerMax;
		}

		//Refresh of TCP retransmits at 10 Hz
		if(g_logTimer.GetCount() >= next10HzTick)
		{
			g_ethProtocol->OnAgingTick10x();
			next10HzTick = g_logTimer.GetCount() + 1000;

			//also do boot-application timeout
			if(g_bootAppPending)
			{
				g_bootAppTimer --;
				if(g_bootAppTimer == 0)
				{
					if(ValidateAppPartition(g_appVector))
						BootApplication(g_appVector);
					else
						g_log(Logger::ERROR, "Application partition failed to boot\n");

					g_bootAppPending = false;
				}
			}
		}

		//1 Hz timer for various aging processes
		if(g_logTimer.GetCount() >= next1HzTick)
		{
			g_ethProtocol->OnAgingTick();
			next1HzTick = g_logTimer.GetCount() + 10000;
		}
		*/
	}
}

void RegisterProtocolHandlers(IPv4Protocol& ipv4)
{
	//TODO
}

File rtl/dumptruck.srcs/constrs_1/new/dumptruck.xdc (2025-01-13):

########################################################################################################################
# IO pinout constraints

set_property IOSTANDARD LVCMOS33 [get_ports {bank16_io_3v3[49]}]
set_property IOSTANDARD LVCMOS33 [get_ports {bank16_io_3v3[48]}]
set_property IOSTANDARD LVCMOS33 [get_ports {bank16_io_3v3[47]}]
set_property IOSTANDARD LVCMOS33 [get_ports {bank16_io_3v3[46]}]
set_property IOSTANDARD LVCMOS33 [get_ports {bank16_io_3v3[45]}]
set_property IOSTANDARD LVCMOS33 [get_ports {bank16_io_3v3[44]}]
set_property IOSTANDARD LVCMOS33 [get_ports {bank16_io_3v3[43]}]
set_property IOSTANDARD LVCMOS33 [get_ports {bank16_io_3v3[42]}]
set_property IOSTANDARD LVCMOS33 [get_ports {bank16_io_3v3[41]}]
set_property IOSTANDARD LVCMOS33 [get_ports {bank16_io_3v3[40]}]
set_property IOSTANDARD LVCMOS33 [get_ports {bank16_io_3v3[39]}]
set_property IOSTANDARD LVCMOS33 [get_ports {bank16_io_3v3[38]}]
set_property IOSTANDARD LVCMOS33 [get_ports {bank16_io_3v3[37]}]
set_property IOSTANDARD LVCMOS33 [get_ports {bank16_io_3v3[36]}]
set_property IOSTANDARD LVCMOS33 [get_ports {bank16_io_3v3[35]}]
set_property IOSTANDARD LVCMOS33 [get_ports {bank16_io_3v3[34]}]
set_property IOSTANDARD LVCMOS33 [get_ports {bank16_io_3v3[33]}]
set_property IOSTANDARD LVCMOS33 [get_ports {bank16_io_3v3[32]}]
set_property IOSTANDARD LVCMOS33 [get_ports {bank16_io_3v3[31]}]
set_property IOSTANDARD LVCMOS33 [get_ports {bank16_io_3v3[30]}]
set_property IOSTANDARD LVCMOS33 [get_ports {bank16_io_3v3[29]}]
set_property IOSTANDARD LVCMOS33 [get_ports {bank16_io_3v3[28]}]
set_property IOSTANDARD LVCMOS33 [get_ports {bank16_io_3v3[27]}]
set_property IOSTANDARD LVCMOS33 [get_ports {bank16_io_3v3[26]}]
set_property IOSTANDARD LVCMOS33 [get_ports {bank16_io_3v3[25]}]
set_property IOSTANDARD LVCMOS33 [get_ports {bank16_io_3v3[24]}]
set_property IOSTANDARD LVCMOS33 [get_ports {bank16_io_3v3[23]}]
set_property IOSTANDARD LVCMOS33 [get_ports {bank16_io_3v3[22]}]
set_property IOSTANDARD LVCMOS33 [get_ports {bank16_io_3v3[21]}]
set_property IOSTANDARD LVCMOS33 [get_ports {bank16_io_3v3[20]}]
set_property IOSTANDARD LVCMOS33 [get_ports {bank16_io_3v3[19]}]
set_property IOSTANDARD LVCMOS33 [get_ports {bank16_io_3v3[18]}]
set_property IOSTANDARD LVCMOS33 [get_ports {bank16_io_3v3[17]}]
set_property IOSTANDARD LVCMOS33 [get_ports {bank16_io_3v3[16]}]
set_property IOSTANDARD LVCMOS33 [get_ports {bank16_io_3v3[15]}]
set_property IOSTANDARD LVCMOS33 [get_ports {bank16_io_3v3[14]}]
set_property IOSTANDARD LVCMOS33 [get_ports {bank16_io_3v3[13]}]
set_property IOSTANDARD LVCMOS33 [get_ports {bank16_io_3v3[12]}]
set_property IOSTANDARD LVCMOS33 [get_ports {bank16_io_3v3[11]}]
set_property IOSTANDARD LVCMOS33 [get_ports {bank16_io_3v3[10]}]
set_property IOSTANDARD LVCMOS33 [get_ports {bank16_io_3v3[9]}]
set_property IOSTANDARD LVCMOS33 [get_ports {bank16_io_3v3[8]}]
set_property IOSTANDARD LVCMOS33 [get_ports {bank16_io_3v3[7]}]
set_property IOSTANDARD LVCMOS33 [get_ports {bank16_io_3v3[6]}]
set_property IOSTANDARD LVCMOS33 [get_ports {bank16_io_3v3[5]}]
set_property IOSTANDARD LVCMOS33 [get_ports {bank16_io_3v3[4]}]
set_property IOSTANDARD LVCMOS33 [get_ports {bank16_io_3v3[3]}]
set_property IOSTANDARD LVCMOS33 [get_ports {bank16_io_3v3[2]}]
set_property IOSTANDARD LVCMOS33 [get_ports {bank16_io_3v3[1]}]
set_property IOSTANDARD LVCMOS33 [get_ports {bank16_io_3v3[0]}]
set_property IOSTANDARD LVCMOS12 [get_ports {bank34_io_1v2[49]}]
set_property IOSTANDARD LVCMOS12 [get_ports {bank34_io_1v2[48]}]
set_property IOSTANDARD LVCMOS12 [get_ports {bank34_io_1v2[47]}]
set_property IOSTANDARD LVCMOS12 [get_ports {bank34_io_1v2[46]}]
set_property IOSTANDARD LVCMOS12 [get_ports {bank34_io_1v2[45]}]
set_property IOSTANDARD LVCMOS12 [get_ports {bank34_io_1v2[44]}]
set_property IOSTANDARD LVCMOS12 [get_ports {bank34_io_1v2[43]}]
set_property IOSTANDARD LVCMOS12 [get_ports {bank34_io_1v2[42]}]
set_property IOSTANDARD LVCMOS12 [get_ports {bank34_io_1v2[41]}]
set_property IOSTANDARD LVCMOS12 [get_ports {bank34_io_1v2[40]}]
set_property IOSTANDARD LVCMOS12 [get_ports {bank34_io_1v2[39]}]
set_property IOSTANDARD LVCMOS12 [get_ports {bank34_io_1v2[38]}]
set_property IOSTANDARD LVCMOS12 [get_ports {bank34_io_1v2[37]}]
set_property IOSTANDARD LVCMOS12 [get_ports {bank34_io_1v2[36]}]
set_property IOSTANDARD LVCMOS12 [get_ports {bank34_io_1v2[35]}]
set_property IOSTANDARD LVCMOS12 [get_ports {bank34_io_1v2[34]}]
set_property IOSTANDARD LVCMOS12 [get_ports {bank34_io_1v2[33]}]
set_property IOSTANDARD LVCMOS12 [get_ports {bank34_io_1v2[32]}]
set_property IOSTANDARD LVCMOS12 [get_ports {bank34_io_1v2[31]}]
set_property IOSTANDARD LVCMOS12 [get_ports {bank34_io_1v2[30]}]
set_property IOSTANDARD LVCMOS12 [get_ports {bank34_io_1v2[29]}]
set_property IOSTANDARD LVCMOS12 [get_ports {bank34_io_1v2[28]}]
set_property IOSTANDARD LVCMOS12 [get_ports {bank34_io_1v2[27]}]
set_property IOSTANDARD LVCMOS12 [get_ports {bank34_io_1v2[26]}]
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

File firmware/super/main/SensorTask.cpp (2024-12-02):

/***********************************************************************************************************************
*                                                                                                                      *
* DUMPTRUCK                                                                                                            *
*                                                                                                                      *
* Copyright (c) 2023-2024 Andrew D. Zonenberg and contributors                                                         *
* All rights reserved.                                                                                                 *
*                                                                                                                      *
* Redistribution and use in source and binary forms, with or without modification, are permitted provided that the     *
* following conditions are met:                                                                                        *
*                                                                                                                      *
*    * Redistributions of source code must retain the above copyright notice, this list of conditions, and the         *
*      following disclaimer.                                                                                           *
*                                                                                                                      *
*    * Redistributions in binary form must reproduce the above copyright notice, this list of conditions and the       *
*      following disclaimer in the documentation and/or other materials provided with the distribution.                *
*                                                                                                                      *
*    * Neither the name of the author nor the names of any contributors may be used to endorse or promote products     *
*      derived from this software without specific prior written permission.                                           *
*                                                                                                                      *
* THIS SOFTWARE IS PROVIDED BY THE AUTHORS "AS IS" AND ANY EXPRESS OR IMPLIED WARRANTIES, INCLUDING, BUT NOT LIMITED   *
* TO, THE IMPLIED WARRANTIES OF MERCHANTABILITY AND FITNESS FOR A PARTICULAR PURPOSE ARE DISCLAIMED. IN NO EVENT SHALL *
* THE AUTHORS BE HELD LIABLE FOR ANY DIRECT, INDIRECT, INCIDENTAL, SPECIAL, EXEMPLARY, OR CONSEQUENTIAL DAMAGES        *
* (INCLUDING, BUT NOT LIMITED TO, PROCUREMENT OF SUBSTITUTE GOODS OR SERVICES; LOSS OF USE, DATA, OR PROFITS; OR       *
* BUSINESS INTERRUPTION) HOWEVER CAUSED AND ON ANY THEORY OF LIABILITY, WHETHER IN CONTRACT, STRICT LIABILITY, OR TORT *
* (INCLUDING NEGLIGENCE OR OTHERWISE) ARISING IN ANY WAY OUT OF THE USE OF THIS SOFTWARE, EVEN IF ADVISED OF THE       *
* POSSIBILITY OF SUCH DAMAGE.                                                                                          *
*                                                                                                                      *
***********************************************************************************************************************/

#include "supervisor.h"
#include "SensorTask.h"

uint16_t g_vvbus = 0;
uint16_t g_v3v3 = 0;
uint16_t g_v2v5 = 0;
uint16_t g_v1v8 = 0;
uint16_t g_v1v2 = 0;
uint16_t g_v1v0 = 0;
uint16_t g_vdutvdd = 0;
uint16_t g_vio33 = 0;
uint16_t g_vio25 = 0;
uint16_t g_vio18 = 0;
uint16_t g_vio12 = 0;

uint16_t g_i3v3_sb = 0;
uint16_t g_ivbus = 0;
uint16_t g_i3v3 = 0;
uint16_t g_i2v5 = 0;
uint16_t g_i1v8 = 0;
uint16_t g_i1v2 = 0;
uint16_t g_i1v0 = 0;
uint16_t g_idutvdd = 0;
uint16_t g_iio33 = 0;
uint16_t g_iio25 = 0;
uint16_t g_iio18 = 0;
uint16_t g_iio12 = 0;

uint16_t g_ltcTemp = 0;

void SensorTask::Iteration()
{
	switch(m_index)
	{
		////////////////////////////////////////////////////////////////////////////////////////////////////////////////
		// Temperatures

		//Update MCU temperature
		case 0:
			if(g_adc->GetTemperatureNonblocking(g_mcutemp))
				NextStep();
			break;

		case 1:
			g_ltcTemp = GetLTCTemp() * 256;
			NextStep();
			break;

		////////////////////////////////////////////////////////////////////////////////////////////////////////////////
		// Voltages

		//Read MCU 3.3V rail
		//Don't use the internal ADC, use the INA230 since it's way more accurate
		case 2:
			if(ReadVoltageIteration(INA_3V3_SB, g_3v3Voltage))
				NextStep();
			break;

		//Read VBUS
		case 3:
			if(ReadVoltageIteration(INA_VBUS, g_vvbus))
				NextStep();
			break;

		//Read 3V3
		case 4:
			if(ReadVoltageIteration(INA_3V3, g_v3v3))
				NextStep();
			break;

		//Read 2V5
		case 5:
			if(ReadVoltageIteration(INA_2V5, g_v2v5))
				NextStep();
			break;

		//Read 1V8
		case 6:
			if(ReadVoltageIteration(INA_1V8, g_v1v8))
				NextStep();
			break;

		//Read 1V2
		case 7:
			if(ReadVoltageIteration(INA_1V2, g_v1v2))
				NextStep();
			break;

		//Read 1V0
		case 8:
			if(ReadVoltageIteration(INA_1V0, g_v1v0))
				NextStep();
			break;

		//Read DUT_VDD
		case 9:
			if(ReadVoltageIteration(INA_DUT_VDD, g_vdutvdd))
				NextStep();
			break;

		//Read DUT_VCCIO 3.3V
		case 10:
			if(ReadVoltageIteration(INA_VIO33, g_vio33))
				NextStep();
			break;

		//Read DUT_VCCIO 2.5V
		case 11:
			if(ReadVoltageIteration(INA_VIO25, g_vio25))
				NextStep();
			break;

		//Read DUT_VCCIO 1.8V
		case 12:
			if(ReadVoltageIteration(INA_VIO18, g_vio18))
				NextStep();
			break;

		//Read DUT_VCCIO 1.2V
		case 13:
			if(ReadVoltageIteration(INA_VIO12, g_vio12))
				NextStep();
			break;

		////////////////////////////////////////////////////////////////////////////////////////////////////////////////
		// Currents

		case 14:
			if(ReadCurrentIteration(INA_3V3_SB, g_i3v3_sb))
				NextStep();
			break;

		//Read VBUS
		case 15:
			if(ReadCurrentIteration(INA_VBUS, g_ivbus))
				NextStep();
			break;

		//Read 3V3
		case 16:
			if(ReadCurrentIteration(INA_3V3, g_i3v3))
				NextStep();
			break;

		//Read 2V5
		case 17:
			if(ReadCurrentIteration(INA_2V5, g_i2v5))
				NextStep();
			break;

		//Read 1V8
		case 18:
			if(ReadCurrentIteration(INA_1V8, g_i1v8))
				NextStep();
			break;

		//Read 1V2
		case 19:
			if(ReadCurrentIteration(INA_1V2, g_i1v2))
				NextStep();
			break;

		//Read 1V0
		case 20:
			if(ReadCurrentIteration(INA_1V0, g_i1v0))
				NextStep();
			break;

		//Read DUT_VDD
		case 21:
			if(ReadCurrentIteration(INA_DUT_VDD, g_idutvdd))
				NextStep();
			break;

		//Read DUT_VCCIO 3.3V
		case 22:
			if(ReadCurrentIteration(INA_VIO33, g_iio33))
				NextStep();
			break;

		//Read DUT_VCCIO 2.5V
		case 23:
			if(ReadCurrentIteration(INA_VIO25, g_iio25))
				NextStep();
			break;
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

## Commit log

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2024-10-16 Initial work on schematic
    [1v2_vccio.kicad_sch, 1v8_vccio.kicad_sch, 2v5_vccio.kicad_sch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]
2024-10-17 Initial design mostly done aside from USB connector, review, test points
    [1v2_vccio.kicad_sch, 1v8_vccio.kicad_sch, 2v5_vccio.kicad_sch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]
2024-10-17 Finished initial schematic pass, ready for review
    [3v3_vccio.kicad_sch, ethernet.kicad_sch, main-pcb.kicad_sch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]
2024-10-17 More schematic tweaks and test points
    [1v2_vccio.kicad_sch, 1v8_vccio.kicad_sch, 2v5_vccio.kicad_sch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]
2024-10-18 Added some RGB LEDs, changed a few voltage dividers to match what was in stock. Time for next round of review.
    [1v2_vccio.kicad_sch, 1v8_vccio.kicad_sch, 2v5_vccio.kicad_sch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]
2024-10-18 Updated layout and 3D models
    [main-pcb.kicad_pcb]
2024-10-18 Finished schematic review
    [1v2_vccio.kicad_sch, 1v8_vccio.kicad_sch, 2v5_vccio.kicad_sch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]
2024-10-18 First DUT socket fully routed
    [1v2_vccio.kicad_sch, 1v8_vccio.kicad_sch, 2v5_vccio.kicad_sch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]
2024-10-18 Continued initial layout of 1.8V bank
    [main-pcb.kicad_pcb]
2024-10-19 Continued layout mostly of DUT connectors
    [1v2_vccio.kicad_sch, 1v8_vccio.kicad_sch, 2v5_vccio.kicad_sch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]
2024-10-19 1088 unrouted
    [2v5_vccio.kicad_sch, main-pcb.kicad_pcb]
2024-10-19 Continued routing
    [2v5_vccio.kicad_sch, main-pcb.kicad_pcb]
2024-10-20 Continued routing 3V3 DUT socket
    [3v3_vccio.kicad_sch, main-pcb.kicad_pcb]
2024-10-20 Started work on main CPU routing
    [3v3_vccio.kicad_sch, main-pcb.kicad_pcb, mcu.kicad_sch]
2024-10-20 Continued routing MCU, started work on PHY
    [1v2_vccio.kicad_sch, 1v8_vccio.kicad_sch, 2v5_vccio.kicad_sch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]
2024-10-20 Continued routing MCU
    [main-pcb.kicad_pcb, mcu.kicad_sch]
2024-10-21 500 unrouted, still lots more to go
    [ethernet.kicad_sch, main-pcb.kicad_pcb, mcu.kicad_sch]
2024-10-21 Began routing supervisor
    [main-pcb.kicad_pcb]
2024-10-21 Under 400 unrouted
    [main-pcb.kicad_pcb, psu.kicad_sch, rgb.kicad_sch]
2024-10-21 Continued routing RGMII PHY
    [ethernet.kicad_sch, main-pcb.kicad_pcb, psu.kicad_sch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]
2024-10-21 Almost fully routed MCU
    [ethernet.kicad_sch, main-pcb.kicad_pcb, mcu.kicad_sch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]
2024-10-23 Fully routed except for power supply
    [main-pcb.kicad_pcb]
2024-10-23 Began layout of power supply
    [ethernet.kicad_sch, main-pcb.kicad_pcb]
2024-10-23 Continued routing power supply
    [main-pcb.kicad_pcb, psu.kicad_sch]
2024-10-23 Continued layout, added first ground plane layer. 26 nets unrouted, still need to place last two INA230s
    [1v2_vccio.kicad_sch, 1v8_vccio.kicad_sch, 2v5_vccio.kicad_sch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]
2024-10-24 Updating file: main-pcb with current completely routed design
    [main-pcb.kicad_pcb]
2024-10-24 Routing cleanup around MCU, fixed some DRC errors
    [1v2_vccio.kicad_sch, 1v8_vccio.kicad_sch, 2v5_vccio.kicad_sch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]
2024-10-24 Finished initial plane layout, DRC clean
    [rgb.kicad_sch]
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2024-10-30 Updated fab notes to reflect new ground plane thickness and gerber rev
2024-10-30 Added incomplete breakout for 152 ball ONFI, seems the socket isn't useful
    [onfi-152-ball.kicad_pcb, onfi-152-ball.kicad_sch, onfi-152-socket.step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]
2024-10-31 Initial version of dip8-qspi
    [dip8-qspi.kicad_pcb, dip8-qspi.kicad_sch]
2024-11-20 Initial version of CSP56 NOR breakout
    [parallel-nor-csp56.kicad_pcb, parallel-nor-csp56.kicad_sch]
2024-11-25 Initial version of jtag-interposer
    [jtag-interposer.kicad_pcb, jtag-interposer.kicad_sch]
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2024-11-30 dip8-qspi: changed eeprom address to 0xa2
    [dip8-qspi.kicad_pcb, dip8-qspi.kicad_sch]
2024-11-30 parallel-nor-csp56: fixed eeprom address
    [parallel-nor-csp56.kicad_pcb, parallel-nor-csp56.kicad_sch]
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2024-12-03 Initial version of dfn8-small-qspi breakout
    [dfn8-small-qspi.kicad_pcb, dfn8-small-qspi.kicad_sch]
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2024-12-12 dfn8-small-qspi: fixed incorrect alignment peg position
    [dfn8-small-qspi.kicad_pcb]
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2024-12-24 Added soic8-wide breakout
    [soic8-wide.kicad_pcb, soic8-wide.kicad_sch]
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2025-04-01 Initial version of qspi-soic8-small board
    [qspi-soic8-small-interposer.kicad_pcb, qspi-soic8-small-interposer.kicad_sch]
2025-04-01 Initial version of qspi-soic8-small-host
    [qspi-soic8-small-host.kicad_pcb, qspi-soic8-small-host.kicad_sch, qspi-soic8-small-interposer.kicad_pcb]
2025-04-01 Initial version of qspi-soic8-small-interposer
    [qspi-interposer.kicad_pcb, qspi-interposer.kicad_sch]
2025-04-02 Initial implementation of qspi-extender
    [qspi-extender.kicad_pcb, qspi-extender.kicad_sch]
2025-04-03 Initial version of ram-expansion
    [ram-expansion.kicad_pcb, ram-expansion.kicad_sch]
2025-04-03 qspi-extender: v0.3 with thinner tracks
    [qspi-extender.kicad_pcb]
2025-04-03 Initial version of pin-header adapter
    [pin-header.kicad_pcb, pin-header.kicad_sch]
2025-04-03 Initial version of emmc-interposer
    [emmc-interposer.kicad_pcb, emmc-interposer.kicad_sch]
2025-04-04 Initial version of qspi-mitm board
    [qspi-mitm.kicad_pcb, qspi-mitm.kicad_sch]
2025-04-04 Initial implementation of dfn-8-interposer
    [dfn-8-interposer.kicad_pcb, dfn-8-interposer.kicad_sch]
2025-04-04 Initial implementation of qspi-dfn8-host
    [qspi-dfn8-host.kicad_pcb, qspi-dfn8-host.kicad_sch]
2025-04-04 added 1mm of padding to hit oshpark minimum board size
    [qspi-dfn8-host.kicad_pcb]
